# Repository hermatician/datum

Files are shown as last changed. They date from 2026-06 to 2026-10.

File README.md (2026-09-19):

# datum

A low-profile wireless split keyboard. Fixed, trusted, everything measured from here.

**made by Christian Faurholt**

---

<p align="center">
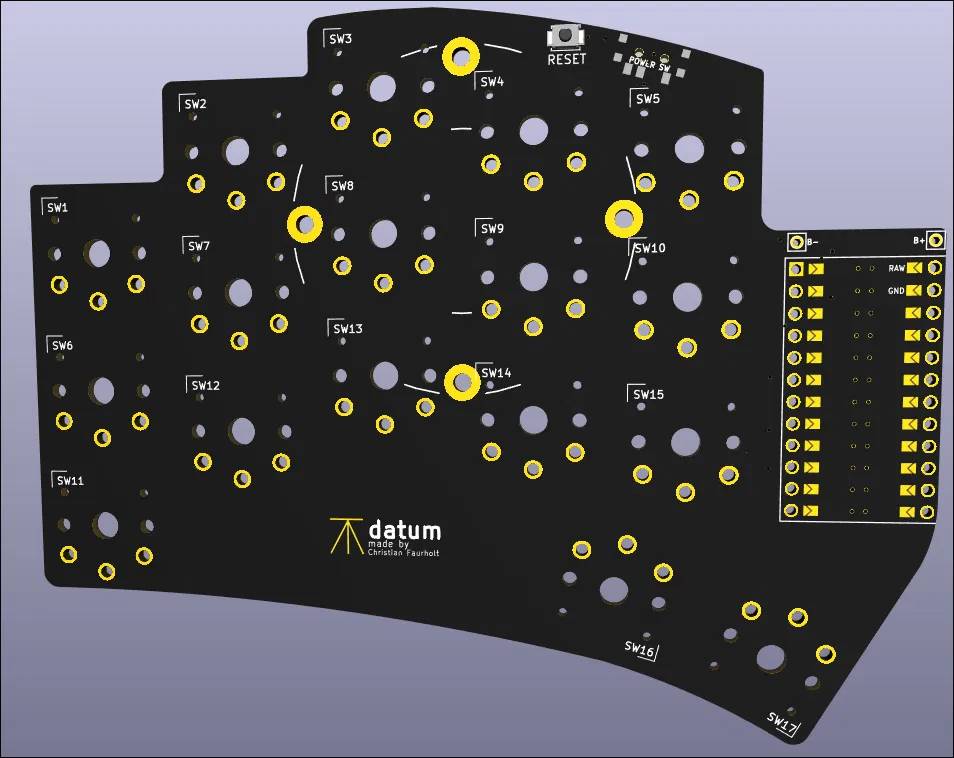
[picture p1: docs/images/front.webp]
datum front
  
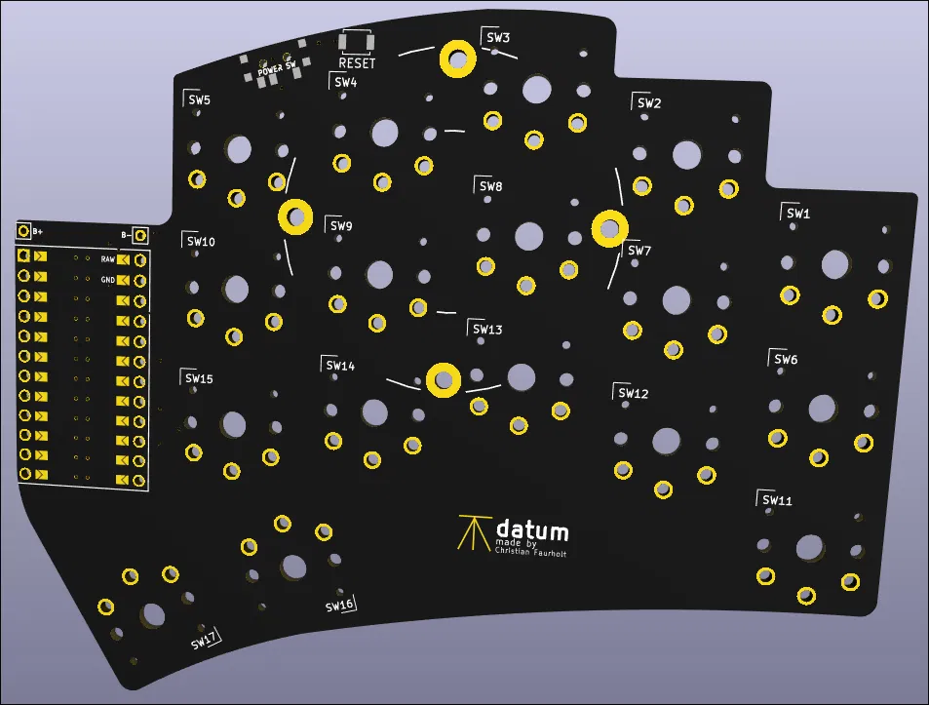
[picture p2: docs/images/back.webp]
datum back
  
</p>

---

## What it is

datum is a 34-key wireless split keyboard based on the Ferris Sweep Half Swept layout, built around a Nice!nano V2 and ZMK firmware. It runs a standard QWERTY layout with Danish OS support — æøå on the base layer, symbols on a dedicated layer, and home row mods for modifiers.

The name comes from surveying. A datum is the fixed reference point from which all other measurements are derived. The benchmark symbol carved into the PCB is the ordnance survey mark used for exactly this purpose — a point cut into stone at a precisely known elevation, against which everything else is measured.

datum is the physical interface to Hermatic. The one fixed, trusted point where the Hermatician touches the system.

---

## Specifications

| Property | Value |
|---|---|
| Layout | 34 keys — 3×5 column stagger + 2 thumb keys per half |
| Controller | Nice!nano V2 (nRF52840, wireless BLE) |
| Firmware | ZMK — QWERTY + Danish OS layout |
| Switches | Ambients Silent Bokeh Choc v1, 50gf |
| Keycaps | MBK Black 1U, Choc spacing 18×17mm |
| PCB | datum — reversible, black soldermask, ENIG finish |
| Build style | Bare PCB, no case, soldered direct |
| Tenting | Splitkb Tenting Puck + Manfrotto Pocket Tripod per half |
| Battery | LiPo 301230 110mAh soldered direct to BAT+/BAT- pads |
| Connection | Wireless BLE only — no TRRS, no USB data in normal use |
| OS layout | Danish |

---

## Components

### PCB

Order from PCBWay using the gerbers in `gerbers/datum_gerbers.zip`:

| Setting | Value |
|---|---|
| Quantity | 10 (minimum order — use 2, keep 8 as spares) |
| Layers | 2 |
| Thickness | 1.6mm |
| Soldermask | Black (Matte) |
| Silkscreen | White |
| Surface finish | Immersion gold (ENIG) |
| Copper weight | 1oz |

### Electronics

| Item | Qty | Source |
|---|---|---|
| Nice!nano V2 | ×2 | Typeractive.xyz |
| Mill-Max Low Profile Sockets 310 series | ×2 sets | Splitkb.com |
| Reset Button — Panasonic SMD | ×2 | Typeractive.xyz |
| Power Switch — Alps SPDT | ×2 | Typeractive.xyz |
| LiPo 301230 110mAh 3.7V | ×2 | — |

### Switches and keycaps

| Item | Qty | Source |
|---|---|---|
| Ambients Silent Bokeh Choc v1 50gf | ×36 | lowprokb.ca |
| MBK Black 1U keycaps | ×36 | lowprokb.ca |
| MBK Black 1U homing keycaps | ×2 | lowprokb.ca |

### Mounting

| Item | Qty | Source |
|---|---|---|
| Splitkb Tenting Puck — Black | ×1 pair | Splitkb.com |
| Manfrotto Pocket Tripod | ×2 | — |
| SKUF Silicone Rubber Feet | ×8 | Splitkb.com |

---

## Firmware

datum uses ZMK firmware with QWERTY + Danish OS layout, home row mods on `s d f g` / `h j k l`, and 6 layers: NAV, SYM, EXT, FN, MEDIA and SETTINGS.

Firmware is built automatically via GitHub Actions. Download the latest build from the [Actions tab](../../actions) — no local toolchain needed.

See [`docs/firmware-guide.md`](docs/firmware-guide.md) for the full layer design and ZMK setup.

See [`docs/keymap-reference.md`](docs/keymap-reference.md) for a quick reference of all layers.

See [`docs/flashing.md`](docs/flashing.md) for flashing instructions.

---

## Building

See [`docs/build-guide.md`](docs/build-guide.md) for full assembly instructions.

Critical notes before you start:

- The PCB is reversible — close the correct jumper pads before soldering anything else
- Battery polarity is critical — reversed polarity will instantly damage the Nice!nano
- Never solder the Nice!nano directly — always use Mill-Max sockets

---

## Repository layout

```
datum/
├── pcb/                      # KiCad project files
├── gerbers/                  # Fabrication files for PCBWay
├── config/                   # ZMK firmware config
│   ├── cradio.keymap         # QWERTY Danish layout, all layers
│   ├── cradio.conf           # ZMK settings
│   └── west.yml              # ZMK dependency
├── build.yaml                # GitHub Actions build matrix
├── docs/
│   ├── build-guide.md        # Assembly instructions
│   ├── build-guide.pdf
│   ├── firmware-guide.md     # ZMK setup and layers
│   ├── firmware-guide.pdf
│   ├── flashing.md           # How to flash firmware
│   ├── keymap-reference.md   # Quick layer reference
│   └── images/               # 3D renders
└── README.md
```

---

## License

MIT

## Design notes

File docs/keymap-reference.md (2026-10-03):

# datum — keymap reference

OS layout: **Danish**

---

## Thumb cluster

```
[ esc/SYM ]  [ spc/NAV ]  |  [ bspc/EXT ]  [ ent/MEDIA ]
```

| Combo | Layer |
|---|---|
| esc + spc | SETTINGS |
| spc + bspc | FN |

---

## Base layer — QWERTY Danish

```
q    w    e    r    t    |    y    u    i    o    p
a    s    d    f    g    |    h    j    k    l    å
z    x    c    v    b    |    n    m    æ    ø    ,
          esc/SYM  spc/NAV  |  bspc/EXT  ent/MEDIA
```

**Home row mods** (hold for modifier, tap for letter):

| Key | Hold |
|---|---|
| s | GUI (Super) |
| d | ALT |
| f | SHIFT |
| g | CTRL |
| h | CTRL |
| j | SHIFT |
| k | ALT |
| l | GUI (Super) |

---

## NAV — Navigation + Numbers

> Activate: hold **spc**

```
1    2    3    4    5    |    6    7    8    9    0
tab  home  ↑   end  pgup |  bspc   ←    ↓    →   del
esc                pgdn  |                        ret
          [  ]  [held]   |  [  ]   [  ]
```

---

## SYM — Symbols

> Activate: hold **esc**

```
!    "    #    $    %    |    &    /    (    )    =
`    -    +    [    {    |    }    ]    _    |    *
~    \    <    >    ?    |    '    :    ;    .    @
         [held]  [  ]   |  [  ]   [  ]
```

---

## EXT — Extended navigation + modifiers

> Activate: hold **bspc**

```
esc                      |  pgup  home   ↑   end  caps
alt  gui  shft ctrl ralt |  pgdn   ←     ↓    →   del
               tab       |        bspc
          [  ]  ctrl     |  [held] [  ]
```

**Note:** Modifiers on the left hand are **sticky** — tap to apply to the next key.

---

## FN — Function keys

> Activate: hold **spc** + **bspc** simultaneously

```
F1   F2   F3   F4   F5   |   F6   F7   F8   F9   F10
F11  F12            caps |        mute vol- vol+
          [  ]  [  ]     |  [  ]   [  ]
```

---

## MEDIA — Media controls

> Activate: hold **ent**

```
                         |
     prev play next      |        mute vol- vol+
          [  ]  [  ]     |  [  ]  [held]
```

---

## SETTINGS — Bluetooth

> Activate: hold **esc** + **spc** simultaneously

```
boot          bt clr bt0 |  bt3        unstk       boot
                    bt1  |  bt4
                    bt2  |  bt5
          [  ]  [  ]     |  [  ]   [  ]
```

| Action | Key |
|---|---|
| Clear all bonds | bt clr |
| Select profile 0-5 | bt0 – bt5 |
| Unstick modifiers | unstk |
| Enter bootloader | boot |

---

## Notes

- `[ ]` = empty / transparent key (passes through to base layer)
- `[held]` = the key being held to activate this layer
- Sticky modifiers (EXT layer left hand) apply once and release automatically

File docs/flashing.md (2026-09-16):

# datum — flashing guide

---

## Requirements

- USB-C cable (must be a data cable, not charge-only)
- Metal tweezers for resetting
- Both `cradio_left` and `cradio_right` `.uf2` firmware files from the [Actions tab](../../actions)

---

## Getting the firmware

1. Go to [github.com/hermatician/datum](https://github.com/hermatician/datum)
2. Click the **Actions** tab
3. Click the latest successful build run
4. Scroll to the bottom and download the **firmware** artifact
5. Unzip — you will find:
   - `cradio_left-nice_nano__zmk-zmk.uf2`
   - `cradio_right-nice_nano__zmk-zmk.uf2`

---

## Entering bootloader mode

The Nice!nano enters bootloader mode when the reset pads are shorted twice quickly.

1. Connect the half you want to flash via USB-C
2. Watch `dmesg` in a terminal:
```bash
sudo dmesg -w
```
3. Short the two reset pads on the PCB twice quickly with metal tweezers
4. Watch for this in dmesg:
```
usb: Product: nice!nano v2
usb-storage: USB Mass Storage device detected
sd: [sda] Attached SCSI removable disk
```

That confirms bootloader mode is active and the controller is ready to flash.

---

## Flashing

```bash
sudo cp ~/Downloads/cradio_left-nice_nano__zmk-zmk.uf2 /dev/sda
sync
```

Then unplug and replug the USB-C cable. Watch dmesg for:
```
usb: Product: datum
```

That confirms the firmware was applied successfully.

Repeat for the right half using `cradio_right-nice_nano__zmk-zmk.uf2`.

---

## After flashing both halves

Power cycle in this order:

1. Power off both halves
2. Power on **right half first**
3. Wait 10 seconds
4. Power on **left half**

The halves will find each other automatically over Bluetooth within 60 seconds.

---

## Re-pairing with your computer

If the keyboard fails to connect after flashing:

```bash
bluetoothctl
remove <MAC address of datum>
scan on
```

Wait for datum to appear, then:

```bash
pair <MAC>
trust <MAC>
connect <MAC>
```

If pairing fails with `AuthenticationFailed`, clear Linux's Bluetooth bond data:

```bash
sudo systemctl stop bluetooth
sudo rm -rf /var/lib/bluetooth/8C:C6:81:14:16:AC/
sudo mkdir /var/lib/bluetooth/8C:C6:81:14:16:AC/
sudo systemctl start bluetooth
```

Then try pairing again.

---

## Notes

- Always flash the left half before the right half
- Use `cp` not `dd` — `dd` may not reliably write the UF2 bootloader
- If `dmesg` shows `error -71`, try a different USB-C cable or USB port
- The bodge wire on the right half's inner thumb key (SW17/B5) is fragile — handle with care

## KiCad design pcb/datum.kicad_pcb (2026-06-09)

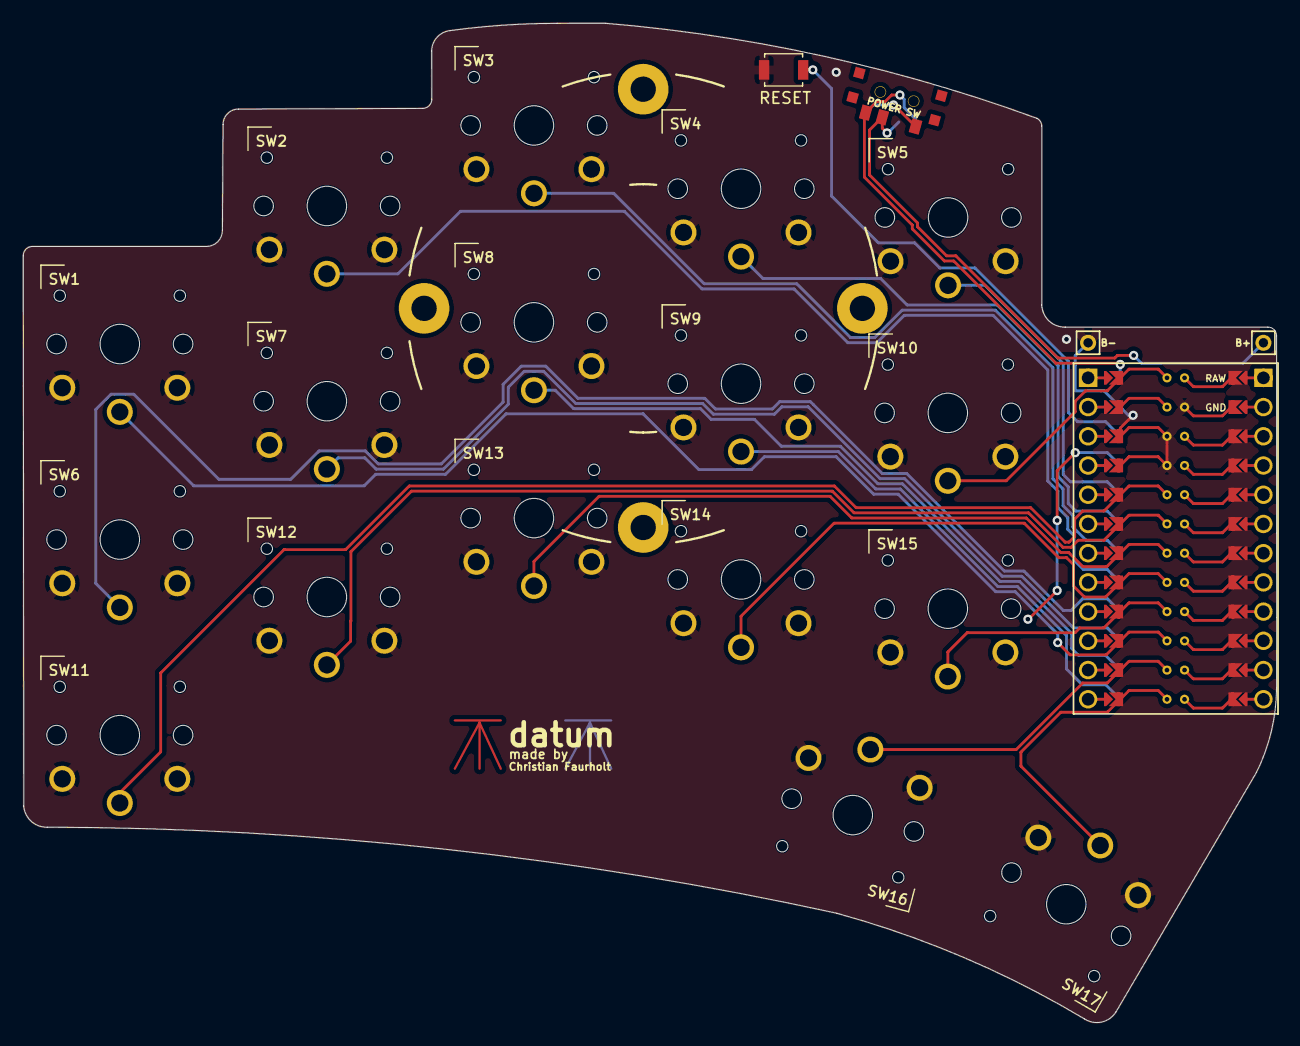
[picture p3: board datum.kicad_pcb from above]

Board: 2 copper layers, 109.0 x 86.9 mm, 22 parts (0 on the bottom side), 21 nets.

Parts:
B+: MountingHole_Pad; 1pin_conn
B-: MountingHole_Pad; 1pin_conn
POWER SW: SW_SPDT; SPDT_C128955
RSW2: SW_Push; Tactile-Switch_SMT
SW1, SW2, SW3, SW4, SW5, SW6, SW7, SW8, SW9, SW10, SW11, SW12, SW13, SW14, SW15, SW16, SW17: SW_Push; SW_PG1350_rev_DPB
U1: ProMicro-kbd; ProMicro_jumpers_facedown

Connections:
BT+_r: B+.1, POWER SW.2
Switch1: SW1.1, U1.10
Switch2: SW2.1, U1.17
Switch3: SW3.1, U1.18
Switch4: SW4.1, U1.19
Switch5: SW5.1, U1.20
Switch6: SW6.1, U1.16
Switch7: SW7.1, U1.15
Switch8: SW8.1, U1.14
Switch9: SW9.1, U1.13
Switch10: SW10.1, U1.1
Switch11: SW11.1, U1.5
Switch12: SW12.1, U1.6
Switch13: SW13.1, U1.7
Switch14: SW14.1, U1.8
Switch15: SW15.1, U1.9
Switch16: SW16.1, U1.11
Switch17: SW17.1, U1.12
gnd: B-.1, RSW2.1, RSW2.2, SW1.2, SW2.2, SW3.2, SW4.2, SW5.2, SW6.2, SW7.2, SW8.2, SW9.2, SW10.2, SW11.2, SW12.2, SW13.2, SW14.2, SW15.2, SW16.2, SW17.2, U1.3, U1.4, U1.23
raw: POWER SW.3, U1.24
reset: RSW2.1, RSW2.2, U1.22

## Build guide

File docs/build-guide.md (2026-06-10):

# datum — build guide

**made by Christian Faurholt**

---

## Before you start

### Critical notes

**The PCB is reversible.**
The same PCB is used for both left and right halves. Jumper pads determine which side it becomes. You must close the correct jumper pads before soldering anything else.

**Battery polarity is critical.**
Reversed polarity will instantly and permanently damage the Nice!nano. Always verify with a multimeter before soldering.

**Never solder the Nice!nano directly.**
Always use Mill-Max sockets. This allows you to remove the controller for firmware flashing or replacement.

---

## Jumper pads

The datum PCB has jumper pads that configure it as either a left or right half.

- **Left half** — close the jumper pads on the **top side** of the PCB
- **Right half** — close the jumper pads on the **bottom side** of the PCB

Bridge the pads with a small amount of solder. Verify with a multimeter in continuity mode that they are correctly bridged before proceeding.

---

## Soldering order

Always solder in this order. Components soldered out of order can be impossible to rework later.

### Step 1 — Power switches

Place the Alps SPDT power switch matching the footprint outline and solder all three legs. Switch orientation matters — match the silkscreen.

Verify with a multimeter: in the OFF position there should be no continuity between BAT+ and RAW.

### Step 2 — Reset buttons

Place the Panasonic SMD reset button matching the footprint and solder all four legs. No orientation required — it is symmetric.

### Step 3 — Mill-Max sockets

1. Insert sockets into the PCB from the **top side**
2. Place tape over the socket openings to prevent solder wicking into the pins
3. Solder from the **underside** of the PCB
4. Remove tape after soldering
5. Verify each socket is flush and not at an angle

Do not insert the Nice!nano yet.

### Step 4 — Battery

**Verify polarity with a multimeter before soldering.**

- Red wire = BAT+ (positive)
- Black wire = BAT- (negative / ground)

Measure wire length before cutting. The battery sits flat under the Nice!nano. Trim to just enough slack to tuck flat — leave a few mm of margin.

Solder red wire to BAT+ and black wire to BAT-. Double-check polarity one more time before proceeding.

### Step 5 — Switches

Solder all 17 switches per half. Press each switch firmly into the PCB until it clicks into place, then solder both pins.

Before soldering, verify each switch position by shorting the pads with tweezers — this saves desoldering later if you find a dead connection.

### Step 6 — Nice!nano

Insert the Nice!nano into the Mill-Max sockets:

- Components face **down**, toward the PCB
- USB-C port faces toward the **inner edge** of the board

Do not solder. The Nice!nano sits in the sockets and can be removed.

---

## Tenting

Start at 10–15 degrees tenting angle. Lock the Manfrotto angle firmly — the SKUF silicone feet prevent the board from sliding on your desk.

---

## Troubleshooting

**A key does not register**
Check the switch pins are fully soldered. Short the switch pads with tweezers — if the key registers, the switch itself is faulty.

**An entire row or column does not register**
Check the solder joints on the controller pads in that row or column.

**The keyboard does not power on**
Check the power switch orientation and verify the battery polarity.

**The halves do not connect wirelessly**
Ensure both halves are powered on. The left half is central — it connects to the computer. The right half connects to the left half. If pairing fails, clear the ZMK bonds and re-pair.

**Nice!nano not detected when flashing**
Double-tap the reset button quickly. If the bootloader does not appear, try a different USB-C cable — some cables are charge-only.

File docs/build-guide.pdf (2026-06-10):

## datum build guide

made by Christian Faurholt

## Before you start

## Critical notes

■ The PCB is reversible.
The same PCB is used for both left and right halves. Jumper pads determine which side it becomes. You must close the correct jumper pads before soldering anything else.

■ Battery polarity is critical.
Reversed polarity will instantly and permanently damage the Nice!nano. Always verify with a multimeter before soldering.

■ Never solder the Nice!nano directly.
Always use Mill-Max sockets. This allows you to remove the controller for firmware flashing or replacement.

## Jumper pads

The datum PCB has jumper pads that configure it as either a left or right half.
- Left half — close the jumper pads on the top side of the PCB
- Right half — close the jumper pads on the bottom side of the PCB
Bridge the pads with a small amount of solder. Verify with a multimeter in continuity mode before proceeding.

## Soldering order

Always solder in this order. Components soldered out of order can be impossible to rework later.

## Step 1 — Power switches

Place the Alps SPDT power switch matching the footprint outline and solder all three legs. Orientation matters — match the silkscreen. Verify with a multimeter: in the OFF position there should be no continuity between BAT+ and RAW.

## Step 2 — Reset buttons

Place the Panasonic SMD reset button matching the footprint and solder all four legs. No orientation required — it is symmetric.

## Step 3 — Mill-Max sockets

Insert sockets from the top side. Place tape over the openings to prevent solder wicking into the pins. Solder from the underside. Remove tape after soldering. Verify each socket is flush. Do not insert the

Nice!nano yet.

## Step 4 — Battery

Verify polarity with a multimeter before soldering. Red wire = BAT+ (positive). Black wire = BAT-(negative/ground). Measure wire length before cutting — battery sits flat under the Nice!nano. Solder red to BAT+ and black to BAT-. Double-check polarity before proceeding.

## Step 5 — Switches

Solder all 17 switches per half. Press each switch firmly until it clicks, then solder both pins. Before soldering, verify each position by shorting the pads with tweezers.

## Step 6 — Nice!nano

Insert into Mill-Max sockets. Components face down toward the PCB. USB-C port faces toward the inner edge of the board. Do not solder — it sits in the sockets and can be removed.

## Tenting

Start at 10–15 degrees. Lock the Manfrotto angle firmly — SKUF feet prevent sliding.

## Troubleshooting

A key does not register
Check switch pins are fully soldered. Short the switch pads with tweezers — if the key registers, the switch is faulty.
An entire row or column does not register
Check solder joints on the controller pads in that row or column.
The keyboard does not power on
Check power switch orientation and verify battery polarity.
The halves do not connect wirelessly
Both halves must be powered on. Left half is central. If pairing fails, clear ZMK bonds and re-pair. Nice!nano not detected when flashing
Double-tap reset quickly. Try a different USB-C cable — some cables are charge-only.

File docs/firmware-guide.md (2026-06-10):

# datum — firmware guide

---

## Overview

datum uses ZMK firmware. The keyboard presents as the Cradio shield to ZMK.

Firmware is built automatically via GitHub Actions whenever you push changes to `config/`. No local toolchain needed — the `.uf2` files are downloadable directly from the Actions tab.

---

## Getting the firmware

1. Go to [github.com/hermatician/datum](https://github.com/hermatician/datum)
2. Click the **Actions** tab
3. Click the latest successful build run
4. Scroll to the bottom and download the **firmware** artifact
5. Unzip — you will find two files:
   - `cradio_left-nice_nano-zmk.uf2`
   - `cradio_right-nice_nano-zmk.uf2`

---

## Flashing

1. Connect the Nice!nano via USB-C
2. Double-tap the reset button to enter bootloader mode — a USB drive called **NICENANO** appears
3. Copy the `.uf2` file onto the drive
4. The controller reboots automatically

Flash the left half first using `cradio_left-nice_nano-zmk.uf2`, then the right half using `cradio_right-nice_nano-zmk.uf2`.

---

## Modifying the keymap

The keymap lives at `config/cradio.keymap` in the datum repo. Edit it and push — GitHub Actions will build new firmware automatically.

---

## Base layout — Gallium (columnar stagger variant)

datum uses the Gallium layout, optimised specifically for columnar stagger keyboards. Gallium is designed to minimise same-finger bigrams, reduce lateral stretch, and balance finger load — all of which matter more on a 34-key board than on a full-size keyboard.

```
b  l  d  c  v  |  j  y  o  u  ,
n  r  t  s  g  |  p  h  a  e  i
x  q  m  w  z  |  k  f  '  ;  .
          NAV SPC | BSPC SYM
```

Home row left: `n r t s` — the most common consonants in English, all on strong fingers.
Home row right: `p h a e i` — high frequency letters, all on strong fingers.

### Why Gallium for datum

- Lowest same-finger bigrams of the mainstream alt layouts on columnar stagger
- `h` on the vowel hand index breaks up vowel clusters — critical for Rust identifiers
- Comma and period on the right hand bottom row — natural for Rust's `,` and `..` syntax
- Hand balance close to 50/50 for extended sessions

### Learning Gallium

Gallium is a significant departure from QWERTY. Budget 2–4 weeks to reach comfortable typing speed. Use [Monkeytype](https://monkeytype.com) with a custom Gallium layout for daily practice.

A useful progression:
1. Learn home row first: `n r t s` / `p h a e i`
2. Add top row: `b l d c v` / `j y o u ,`
3. Add bottom row: `x q m w z` / `k f ' ; .`
4. Only then add layers and combos

---

## Layer design

### Base layer — Gallium

```
b  l  d  c  v  |  j  y  o  u  ,
n  r  t  s  g  |  p  h  a  e  i
x  q  m  w  z  |  k  f  '  ;  .
          NAV SPC | BSPC SYM
```

- Left thumb tap: **Space** / hold: **NAV layer**
- Right thumb tap: **Backspace** / hold: **SYM layer**

### Layer 1 — Navigation + Numbers

```
1    2    3    4    5    |  6     7     8     9    0
TAB  HOME UP   END  PGUP |  BSPC  LEFT  DOWN  RIGHT DEL
ESC  —    —    —    PGDN |  —     —     —     —    RET
              [held] SPC |  BSPC  FN
```

### Layer 2 — Symbols

```
!   @   #   $   %   |  ^   &   *   (   )
`   -   =   [   {   |  }   ]   +   _   ;
~   |   \   <   >   |  ::  "   '   :   ?
          NAV SPC   |  BSPC [held]
```

Note: `::` as a single key — typed constantly in Rust.

### Layer 3 — Function + System

```
F1  F2  F3  F4  F5  |  F6  F7   F8    F9   F10
F11 F12  —   —  CAPS|  —   MUTE VOLD  VOLU  —
BOOT —   —   —   —  |  —    —    —     —     —
          [held] SPC |  BSPC [held]
```

**BOOT** = ZMK bootloader mode for flashing. Both thumbs held activates this layer.

---

## Home row mods

On a 34-key board, modifiers live on the home row as tap-hold keys. This keeps your fingers on the home row at all times.

```
Left hand:   n=GUI  r=ALT  t=SHIFT  s=CTRL
Right hand:  p=GUI  h=ALT  a=SHIFT  e=CTRL
```

ZMK tap-hold settings used in datum:

```
tapping-term-ms: 200
flavor: balanced
require-prior-idle-ms: 150
```

The `require-prior-idle-ms` setting is the most important — it prevents accidental modifier activation during fast typing by requiring a brief pause before a hold registers.

---

## Combos

```
J + K simultaneously  →  ::
M + ,  simultaneously  →  ->
, + .  simultaneously  →  =>
```

These target the most common Rust-specific sequences that would otherwise require layer switching.

---

## Build details

| Property | Value |
|---|---|
| Shield | cradio (Ferris Sweep / Cradio) |
| Board | nice_nano//zmk (Nice!nano V2, Zephyr 4.1+) |
| ZMK revision | main |
| Build trigger | push to config/ or workflow_dispatch |

---

## Resources

- ZMK docs: [zmk.dev/docs](https://zmk.dev/docs)
- Gallium layout: [github.com/GalileoBlues/Gallium](https://github.com/GalileoBlues/Gallium)
- Monkeytype for practice: [monkeytype.com](https://monkeytype.com)
- datum repo: [github.com/hermatician/datum](https://github.com/hermatician/datum)

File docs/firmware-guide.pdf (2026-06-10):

# datum

## firmware guide

made by Christian Faurholt

## Overview

datum uses ZMK firmware, built automatically via GitHub Actions whenever you push changes to config/. No local toolchain needed — the .uf2 files are downloadable directly from the Actions tab.

## Getting the firmware

1. Go to github.com/hermatician/datum
2. Click the Actions tab
3. Click the latest successful build run
4. Scroll to the bottom and download the firmware artifact
5. Unzip — you will find cradio_left-nice_nano-zmk.uf2 and cradio_right-nice_nano-zmk.uf2

## Flashing

1. Connect the Nice!nano via USB-C
2. Double-tap the reset button — a USB drive called NICENANO appears
3. Copy the .uf2 file onto the drive
4. The controller reboots automatically
5. Flash left half first with cradio_left-nice_nano-zmk.uf2, then right half

## Modifying the keymap

The keymap lives at config/cradio.keymap in the datum repo. Edit it and push — GitHub Actions will build new firmware automatically.

## Base layout — Gallium (columnar stagger variant)

datum uses the Gallium layout, optimised specifically for columnar stagger keyboards.

b l d c v | j y o u ,
n r t s g | p h a e i
x q m w z | k f ' ; .
NAV SPC | BSPC SYM
Home row left: n r t s — the most common consonants, all on strong fingers. Home row right: p h a e i — high frequency letters, all on strong fingers.

## Learning Gallium

Gallium is a significant departure from QWERTY. Budget 2–4 weeks to reach comfortable typing speed. Use Monkeytype for daily practice.
1. Learn home row first: n r t s / p h a e i
2. Add top row: b l d c v / j y o u ,
3. Add bottom row: x q m w z / k f ' ; .

4. Only then add layers and combos

## Layer design

## Base layer

Left thumb: tap = Space / hold = NAV Right thumb: tap = Backspace / hold = SYM

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

## Layer 1 — Navigation + Numbers

1 | 2 | 3 | 4 | 5 | | 6 | 7 | 8 | 9 | 0
TAB HOME UP | END PGUP | BSPC LEFT DOWN RIGHT DEL
ESC -- | -- | -- | PGDN | -- | -- | -- | -- | RET
[held] SPC | BSPC FN

## Layer 2 — Symbols

! | @ | # | $ | % | | ^ | & | * | ( | )
` | - | = | [ | { | | } | ] | + | _ | ;
~ | | | \ | < | > | | :: " | ' | : | ?
NAV SPC | | BSPC [held]
:: as a single key — typed constantly in Rust.

## Layer 3 — Function + System

F1 F2 F3 F4 F5 | F6 F7 | F8 | F9 | F10
F11 F12 -- -- CAPS| -- MUTE VOLD VOLU --
BOOT -- -- -- -- | -- | -- | -- | -- | --
[held] SPC | BSPC [held]
BOOT = ZMK bootloader mode. Both thumbs held activates this layer.

## Home row mods

Modifiers live on the home row as tap-hold keys, keeping your fingers on the home row at all times.

Left: n=GUI r=ALT t=SHIFT s=CTRL
Right: p=GUI h=ALT a=SHIFT e=CTRL

tapping-term-ms: 200
flavor: balanced
require-prior-idle-ms: 150

## Combos

J + K simultaneously -> :: M + , simultaneously -> -> , + . simultaneously -> =>

## Build details

Property | Value
Shield | cradio (Ferris Sweep / Cradio)
Board | nice_nano//zmk (Nice!nano V2, Zephyr 4.1+)

ZMK revision | main
Build trigger | push to config/ or workflow_dispatch

## Resources

- ZMK docs: zmk.dev/docs
- Gallium layout: github.com/GalileoBlues/Gallium
- Monkeytype: monkeytype.com
- datum repo: github.com/hermatician/datum

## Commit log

2026-06-09 init: base from Sweep Half Swept
    [half-swept.kicad_pcb, half-swept.kicad_sch]
2026-06-09 init: rename Sweep Half Swept base to datum
    [datum.kicad_pcb, datum.kicad_sch]
2026-06-09 cleanup: remove Sweep Half Swept branding and TRRS footprint
    [datum.kicad_pcb]
2026-06-09 silkscreen: add datum branding and benchmark logo to both sides
    [datum.kicad_pcb]
2026-06-09 pcb: datum board design complete — custom edge cuts and branding
    [datum.kicad_pcb]
2026-06-09 gerbers: add fabrication files
    [datum-B_Cu.gbr, datum-B_Mask.gbr, datum-B_Paste.gbr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]
2026-06-10 docs: add build guide, 3D renders, and gerbers
    [datum-B_Cu.gbr, datum-B_Mask.gbr, datum-B_Paste.gbr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]
2026-06-10 fix: update build.yaml board name for ZMK
2026-06-10 fix: use nice_nano board name for Zephyr 4.1 compatibility
2026-06-10 fix: use nice_nano//zmk board variant for Zephyr 4.1
2026-07-09 firmware: set Bluetooth device name to datum
2026-07-24 fix: rename macro labels to avoid devicetree conflicts
2026-07-24 keymap: change DEL to ESC on left outer thumb, fix settings layer
